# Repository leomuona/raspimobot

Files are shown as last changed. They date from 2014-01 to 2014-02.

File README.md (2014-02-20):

raspimobot
==========

This software project was done for the course Intelligent Embedded System (id 582711) at the CS Department of the University of Helsinki. The course was held during Spring term 2014, third period.

raspimobot is a Raspberry Pi robot that uses camera module and L293D motor control chip to control a single motor. The robot detects movement with the camera and turns the camera (with the motor) towards the movement position. It also supports the use of .wav audio files to greet the person that causes the movement.

This code is under GPLv3 license, please check the LICENSE file for more information.

We used the following libraries and documentation for the project, also includes our demo video:

WiringPi for GPIO controls: http://wiringpi.org

Raspberry Pi userland code for the camera: https://github.com/raspberrypi/userland

Raspberry Pi documentation: http://elinux.org/RPi_Hub

Our demonstration video: http://www.youtube.com/watch?v=bQQ_EZM07OI

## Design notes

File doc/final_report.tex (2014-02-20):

\documentclass[english,11pt,twoside,a4paper]{article}
\usepackage[left=2cm,top=1cm,right=2cm,nohead,nofoot]{geometry}
\usepackage[utf8]{inputenc}
\usepackage{hyperref}
\usepackage{amssymb}
\usepackage{graphicx}
\usepackage{titling}
\newcommand{\subtitle}[1]{%
  \posttitle{%
    \par\end{center}
    \begin{center}\large#1\end{center}
    \vskip0.5em}%
}

\begin{document}
\author{
  Niemistö, Jesse
  \and
  Muona, Leo
  \and
  Hilden, Matias
}
\title{Raspberry Pi robot}
\subtitle{Intelligent Embedded Systems - Final report}

\maketitle

\tableofcontents

\section{Introduction}

This is a final report for the course Intelligent Embedded System (id 582711) at the CS Department of the University of Helsinki. This course was held during Spring term 2014, third period. The course is a self-study course that consists of an embedded systems project. For our project we chose to build a Raspberry Pi robot, which utilizes Pi's camera module, audio output and electric DC motors.

Raspberry Pi is a cheap arm-computer that was originally created for the purpose to help more people to get into programming. We chose to use this one-chip-computer for our project because it runs on Linux (among other operating systems), it has a camera module available, it has GPIO pins for controlling a motor control chip, and all of our team members already had one lying around.

This document includes our project idea, requirements and initial design for the robot, implementation of the robot, evaluation of our project, and a summary of lessons learned. This is the tale of our awesome little raspi robot.

\section{The idea}

We got our initial idea from the video game Portal by Valve Corp. In the game, there were these "cute" robot turrets that recognized movement, talked to the source of the movement and shot them. So our initial idea was to create a robot similar to these turrets, so that we will use Raspberry Pi's camera module to recognize movement, target the movement source, and play a random audio clip to greet the source of the movement.

Our initial idea had two DC motors to control the turret's movement and a laser- or LED-pointer to point the target. However this idea evolved during the project just to use one motor and only turn the camera towards the movement source.

\section{Requirements and initial design}

At the start of our project we wrote our requirements and then initial design. The design consists more on actual planning of hardware part than the code to be created. This section can be divided into five parts: required features, audio system design, camera design, motor control system design, and software design.

\subsection{Required features}

These were the required features at the start of our project when designing the robot:

\begin{itemize}
  \item Horizontal and vertical rotational movement.
  \item WAV (or ogg) audio playback.
  \item Motion detection based on frame difference algorithm.
  \item Aiming at detected movement.
  \item Remote control.
  \item Works on top of Linux.
\end{itemize}

We used these features a guideline for our project design. At this stage it is good to mention that some of these features were modified during the project.

\subsection{Audio design}
\label{sec:audio_design}

For audio we used the 3.5mm jack audio output connector on the Raspberry Pi with our self-built audio amplifier, which is connected to a single speaker. The single speaker can only output mono audio, but this won't matter since audio contains only speaking. The used speaker was small and low powered. We also made a simple audio jack connector. This was made with a bought 3.5mm mono jack connector, which was soldered to ground and audio.

\begin{figure}
  \begin{center}
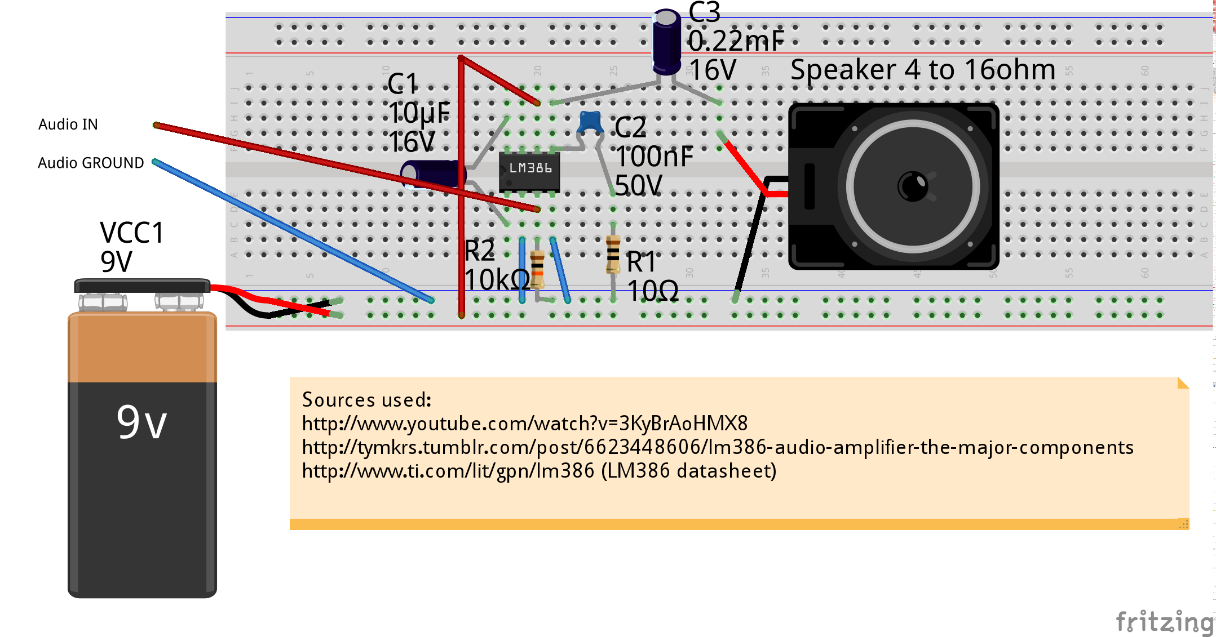
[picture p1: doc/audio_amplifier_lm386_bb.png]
    
    \caption{Breadboard view for the audio amplifier.}
  \end{center}
  \label{lm386_bb}
\end{figure}

In the heart of the audio amplifier stands the LM386 circuit, which is a "Low Voltage Audio Power Amplifier" and was more than enough for our use case. The figure in~\ref{lm386_bb} shows the breadboard view that we used used for the audio amplifier. The build is same to that what is shown on the LM386 datasheet, "amplifier with Gain = 200".

\begin{itemize}
  \item Between PINs 1 and 8 is a 10uF capacitor, which causes a gain on 200. In desibels this is around 20.
  \item PIN 2 is places to ground.
  \item PIN 3 takes the audio input, and is connected to ground through 10k ohm resistor.
  \item PIN 4 is placed to ground.
  \item PIN 5 is the amplified audio output.
  \item PIN 6 takes power
  \item PIN 7 is bybassed, doesn't take connection.
\end{itemize}

\subsection{Camera design}

We decided to use a simple plug-in Raspberry Pi camera module, which we will use to take pictures that we compare to previous ones to detect movement. Since Raspberry Pi has a ready-to-use socket for camera cable, no extra cables or power supplies are needed. To use the camera we will use \href{https://github.com/raspberrypi/userland}{Pi's Userland code}, that comes with raspistill-program which we can use to take still pictures.

\subsection{Motor control design}

To control the motors, we planned our design around L293D motor control chip, which is cheap and easily available. Our design consisted of two motors, one to turn the camera horizontally and one to turn the camera vertically. This design used two L293D chips, one for each motor.

\begin{figure}
  \begin{center}
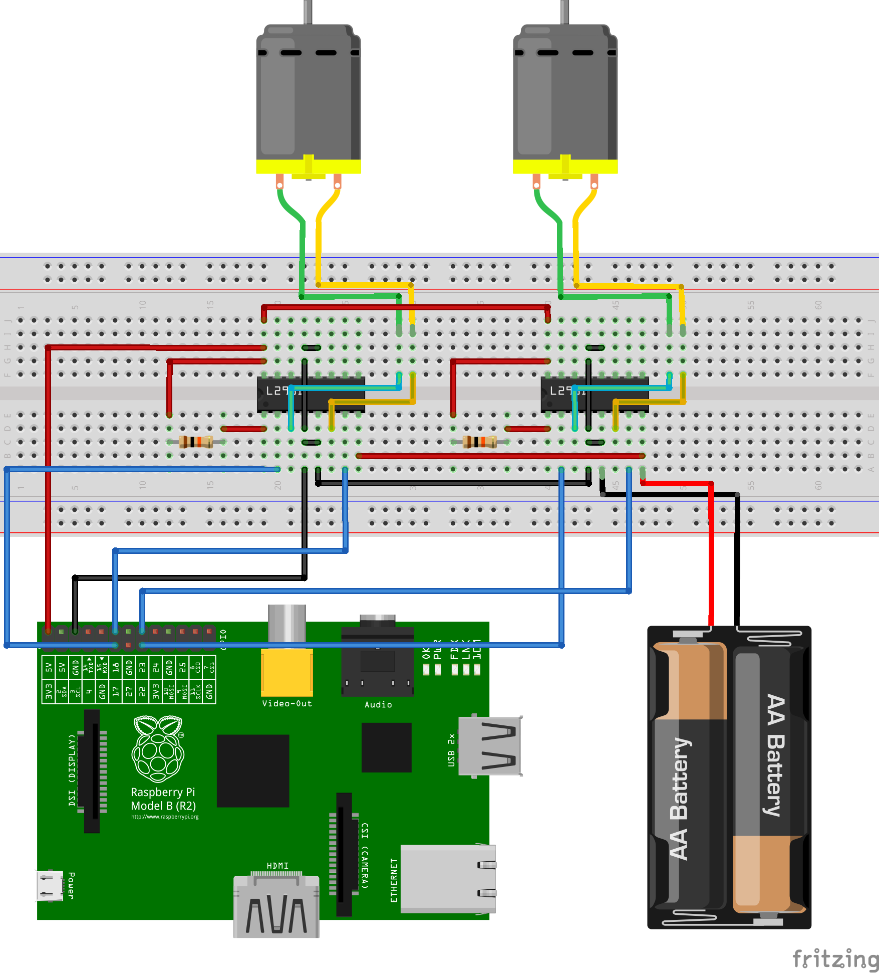
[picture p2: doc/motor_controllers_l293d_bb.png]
    
    \caption{Motor controllers design in breadboard view.}
  \end{center}
  \label{l293d_bb_design}
\end{figure}

Figure \ref{l293d_bb_design} shows how the chips would be connected into the Raspberry Pi. Design uses GPIO pins 17 and 18 to control the first motor and pins 22 and 23 to control the second motor. The two AA batteries will supply power for both of the motors, and Raspberry Pi will supply power for the motor control chips.

\subsection{Software design}

Our project requires software for three main things: camera control, audio control and motor control. Even though we use a ready-to-use software to take pictures with the camera, we need to write our own software for image analysis, that is used to detect movement in the camera. We will write our own audio playback code against pulseaudio sound server. As for sound files, we are planning to use .ogg files. For the motor controlling we plan to use either direct /dev/mem code, or an additional \href{http://wiringpi.com}{WiringPi gpio library} to control the GPIO pins.

We will also write other code, like the logical code for the whole software, threading for different parts, and a remote control code for testing purposes. And hopefully we don't need to write multiple hacks.

\section{Implementation}

For the implementation, we ran into few problems along the way. Implementation was divided into three separate parts: motor related stuff, audio related stuff and camera related stuff. These parts were implemented as paraller. During the implementation, few features needed some modification and later of the project timetable few "nasty" code and hacks were implemented to get the wanted results.

\subsection{Audio}

The implementation of the audio amplifier required bying the parts and assembling them. There weren't really any problems with this, and everything worked as was planned. Refer to chapter~\ref{sec:audio_design} for what was the plan.

The speaker didn't require any assembling but was simply connected to the audio amplifier. For the case of our speaker we used a beer can. Twas used for flavor.

The software part wasn't that easy. We used Pulseaudio audio system for interacting with the underlying audio hardware. We decided to use the Pulseaudio provided Threaded API, as we wanted to play sounds in a non-blocking way. The Initial implementation worked well on test cases, and on development computers. However, when moved to the actual enviroment, which was Raspberry Pi under load, the problems started. Firstly, Pulseaudio allows under no conditions connections from a root user. This caused a few problems as our software at the time required root user (wiring Pi actually). After working around this (dropping root), we noticed that audio was crackling as Raspberry Pi couldn't handle all the load. This required making some things sleep during audio playback.

This wasn't all thought. It seems that at least on the current Raspberry Pi board something with the audio driver or Pulseaudio was bugging, and the whole audio playback would jam for some unknown reason. Working around this actually required a erally evil workaround. Luckily all our samples were really short (under three seconds), so if we notice that three seconds has passed by and our audio subsystem says it is still playing, we send SIGINT to pulseaudio to kill the connection. This made it possible that our robot is able to continue its smooth operation.

\subsection{Motor control system}

Largest modifications to the design had to be done to the motor controlling system. After implementing the planned two-motor-system, we noticed that it would be hard to create correct platform that would be aimed in two dimensions. In addition to this, we noticed that we couldn't implement the correct calculations for vertical movement during project's timetable. Thus we changed the motor system to use only horizontal motor.

\begin{figure}
  \begin{center}
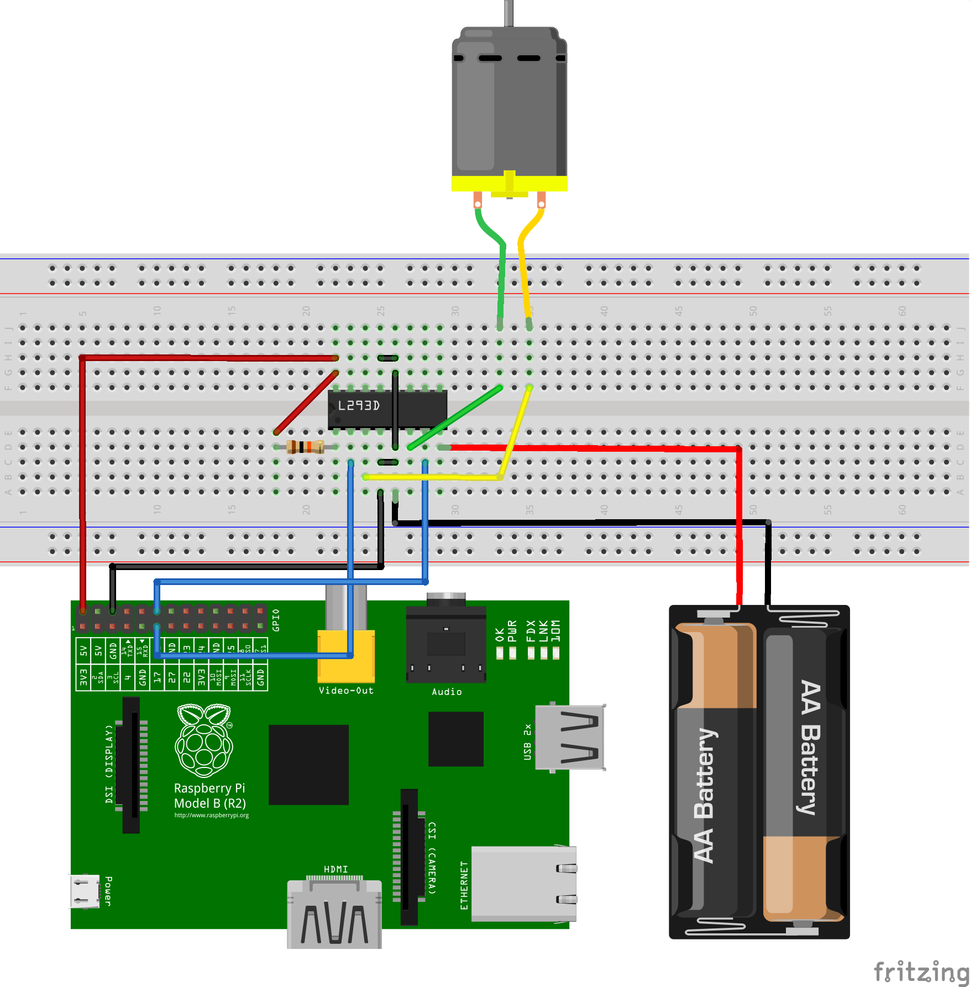
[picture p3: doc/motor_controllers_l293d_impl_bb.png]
    
    \caption{Motor controller implementation in breadboard view.}
  \end{center}
  \label{l293d_bb_impl}
\end{figure}

The hardware implementation of our motor system is shown in figure \ref{l293d_bb_impl}. The AA batteries now have to supply only one motor, and we had to implement code for only two GPIO pins. The L293D motor control chip we used gets it's VCC1 power from Raspberry Pi's 5V pin, and uses that same line trought a 10k ohm resistor to give the enable signal for our motor chip.

Motor control's software had some changes as well. After we started to use \href{http://wiringpi.com}{WiringPi library} the software had to be run as root, as it was WiringPi's requirement. This caused us some problems with pulseaudio, which has a lot of problems when run as root. A fix to this was to remove WiringPi linking from our software and add WiringPi library only as a system requirement. That is, it should be installed on the Raspberry Pi normally. Then we used system calls to use gpio-program, that was bundled with WiringPi and could be run in non-root environments. This is one of the hacks we had to do to get things working.

\subsection{Camera}

Implementing the taking of pictures was not a problem due to the usage of raspistill-program. The program turned to not be optimal for continual usage but served our purposes well enough. Image difference calculation and rotation angle calculation were purely mathematical algorithms and thus did not need to interact with Raspberry Pi hardware. This made their implementation quite straightforward.

\section{Evaluation}

Motor controlling system worked well. Mainly due to the hack we made and the fact that the L293D chip is a pretty simple control chip. Using the GPIO pins is pretty straight forward with the WiringPi library. Only bad thing in the motor control system implementation is that we had to downgrade our project to use only one motor instead of two.

Audio amplifier, when connected to the speaker had suprisingly good sound and volume. Actually we had to drop the volume to one fourth of what was the full volume not to break our ears. The speaker in a can outputted a good and clear sound, better than any of us could have hoped for.

However, when audio jack is not connected, and even sometimes when connected, the audio amplifier and speaker takes audible interference. A high-piched noise that eats into your mind. There were a few workarounds, that mostly was duct taping the wires together which acted as a shield for the wires.

The software side of the Audio, when coupled with the hacks it required, works quite well. At times one can notice that the hardware can't really handle all the load, and audio makes a few cracks. We really shouldn't also have used Pulseaudio Threaded API. This mostly adds overhead, especially since Raspberry Pi is a single processor system.

\section{Summary}

The project started with a funny idea. And the idea continued to live on through the project. Thus all team members agree that this project a great success. There were few hacks along the way and few features had to be modified or dropped, but the robot still was quite similar as the initial idea. Our internal project timetable actually went pretty badly, because implementation took way more time than we originally though. However we were able to get the robot in a complete state.

When analyzing the keys to success, this that comes to mind is the fact that all team members knew each others beforehand, and the project was really fun to work with. Also the amount of documentation for the Raspberry Pi helped alot.

\section{Links}

\begin{itemize}
  \item Demonstration video: \url{http://www.youtube.com/watch?v=bQQ_EZM07OI}
  \item Project github repository: \url{https://github.com/domewolf/raspimobot}
  \item Raspberry Pi userland repository (contains raspistill): \url{https://github.com/raspberrypi/userland}
  \item WiringPi homepage: \url{https://projects.drogon.net/raspberry-pi/wiringpi/}
  \item Raspberry Pi documentations: \url{http://elinux.org/RPi_Hub}
\end{itemize}

\end{document}

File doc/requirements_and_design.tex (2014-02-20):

\documentclass[english,11pt,twoside,a4paper]{article}
\usepackage[left=2cm,top=1cm,right=2cm,nohead,nofoot]{geometry}
\usepackage[utf8]{inputenc}
\usepackage{hyperref}
\usepackage{amssymb}
\usepackage{graphicx}
\begin{document}
\author{
  Niemistö, Jesse
  \and
  Muona, Leo
  \and
  Hilden, Matias
}
\title{Requirements and design}

\maketitle

\section{Introduction}
This document includes requirements, features and design of our turret for Intelligent Embedded Systems -course (University of Helsinki course number 582711). For our project we chose to create an "intelligent" turret inspired by video game Portal by Valve Company. This document describes the intended features that our turret will have. This includes different subsections of the project, including audio output, camera input, DC motor control system and software.

\section{Features}

Robot will have the following features:

\begin{itemize}
  \item Horizontal and vertical rotational movement.
  \item WAV (or ogg) audio playback.
  \item Motion detection based on frame difference algorithm.
  \item Aiming at detected movement.
  \item Remote control.
  \item Works on top of Linux.
\end{itemize}

\section{Audio}

For audio we will be using the 3.5mm jack audio output connector on the raspberry pi. However, instead of connecting just some ready stereo system, we'll build our own audio amplifier, which is connected to a single speaker. Thus we'll only need to output mono audio. Since audio will mostly contain speaking, it does not matter. The used speaker will be small and low powered.

To be able to use our audio amplifier on the raspberry pi, we need to make a simple connector, which is quite simple. We only need to get a male 3.5mm jack connector, ignore the possible second audio output (incase of stereo), and solder our two needed wires on it (ground and audio out).

\begin{figure}
  \begin{center}
    
    \caption{Breadboard view for the audio amplifier.}
  \end{center}
  \label{lm386_bb}
\end{figure}

In the heart of the audio amplifier stands the LM386 circuit, which is a "Low Voltage Audio Power Amplifier" and is more than enough for our use case. The figure in~\ref{lm386_bb} shows the breadboard view that we'll be using for the audio amplifier. The build is same to that what is shown on the LM386 datasheet, "amplifier with Gain = 200".

\begin{itemize}
  \item Between PINs 1 and 8 is a 10uF capacitor, which causes a gain on 200. In desibels this is around 20. 
  \item PIN 2 is places to ground.
  \item PIN 3 takes the audio input, and is connected to ground through 10k ohm resistor.
  \item PIN 4 is placed to ground.
  \item PIN 5 is the amplified audio output.
  \item PIN 6 takes power
  \item PIN 7 is bybassed, doesn't take connection.
\end{itemize}

\section{Camera}
Raspberry Pi Camera Board (https://www.element14.com/picamera) will be used for motion detection together with Raspberry Pi Userland code (https://github.com/raspberrypi/userland). At first, pictures will be taken using the raspistill-program provided by Userland. If we have time, we will integrate the camera code to be part of the other code, thus allowing us to strip all the unneeded features of userland.

Raspberry Pi has a camera socket intended for the camera, so no other electronic components are required in addition to the camera.

\section{Motors}
Lets assume that the turret has a weapon. In implementation the weapon will probably be either a laser pointer or an LED light. Moving the aim into correct position is done by two small DC motors, one for horizontal and one for vertical movement. Raspberry Pi will be controlling the motors via it's PCIO pins.

\begin{figure}
  \begin{center}
    
    \caption{Breadboard view for motor controllers.}
  \end{center}
  \label{l293d_bb}
\end{figure}

Our design uses two L293D motor controller chips for controlling the two motors. The breadboard design in figure \ref{l293d_bb} visualizes more closely on how the L293D chips are connected to Raspberry Pi, motors and additional battery power supply. The design shows how Raspberry Pi's GPIO pins 17 and 18 are used to control the first DC motor, and pins 22 and 23 are used to control the second one. L293D chips will get their VCC1 powers from the 5V Raspberry Pi pin, and their enable powers from the same pin, but trough 10 kilo ohm resistors. The motors will use power from two AA batteries, that give total of 3V voltage for the motors. Power for the motors are given through L293D chip's VCC2 pin.

A compact list for L293D chip's pin usage is the following:
\begin{itemize}
\item Pin 1: Enable signal for control signals \#1 and \#2.
\item Pin 2: Control signal \#1 input from Raspberry Pi.
\item Pin 3: Output current \#1 for the DC motor.
\item Pins 4-5: Ground 0V.
\item Pin 6: Control signal \#2 input from Raspberry Pi.
\item Pin 7: Output current \#2 for the DC motor.
\item Pin 8: VCC2 input, this is the motor's power current.
\item Pins 12-13: Ground 0V.
\item Pin 16: VCC1 power current for the 293D chip.
\end{itemize}

L293D motor control chip makes the DC motor turn left and right when control signals \#1 and \#2 from Raspberry Pi are in different states. If both of them are either low or high, the motor is stopped.

In order to test this design, we will code a simple testing software that gives correct signals from correct Raspberry Pi pins. After the software and signals are tested, then we will attach motor control chips into test bench to test how electronics work while connected. Only after these steps we can assemble our turret's mechanical parts.

\section{Software}
In addition to camera software provided by Raspberry Pi, we will write our own software for image analysis (motion detection), audio playback and motor movement. We will also write a remote control software for testing purposes at some point.

Our audio playback will be coded against pulseaudio sound server. The reason being, that it provides better API than ALSA. For example, there is \href{http://freedesktop.org/software/pulseaudio/doxygen/scache.html}{Sample cache} on the server side, which does sound optimal to what we're planning. We're planning to use ogg for audio files, but we'll see how it goes. We're not sure how much the Arm CPU of the Raspberry Pi can handle, adding ogg decoder on top of everything else might be too much. The first step is to just get somehow working nonblocking audio playback.

Our motor controlling code will use either direct access to /dev/mem or if that does not work, we will use a third party open source library, like \href{http://wiringpi.com/}{WiringPi}.

\end{document}

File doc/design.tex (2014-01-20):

\documentclass[english,11pt,twoside,a4paper]{article}
\usepackage[left=2cm,top=1cm,right=2cm,nohead,nofoot]{geometry}
\usepackage[utf8]{inputenc}
\usepackage{hyperref}
\usepackage{amssymb}
\usepackage{graphicx}
\begin{document}
\author{
  Niemistö, Jesse
  \and
  Muona, Leo
  \and
  Hilden, Matias
}
\title{Conceptual Design}

\maketitle

\section{Project idea}

Our aim in this project is to make a turret, which aims moving targets with laser pointer, and makes appropriate noises. This means that the turret will have following parts:

\begin{itemize}
  \item Raspberry Pi, the main controller. It holds the main software under Linux OS.
  \item Two DC motors (\url{http://www.kouluelektroniikka.fi/cgi-bin/shop.cg?action=prodshow\&usr=3qienj42dm87vuhhkuuv9nst84\&prodid=5561\%20545}), one for horizontal tracking and one for vertical tracking.
  \item Motor control circuit (L293D), which is able to control both motors.
  \item Camera (Raspberry Pi NoIR ccd camera module 5MPx), which is used for tracking movements.
  \item Circuit board, which is used for connections.
  \item Speaker (\url{http://www.partco.biz/verkkokauppa/product\_info.php?cath=17\_1440\_1916\&products\_id=1086})
  \item Audio amplifier, (LM386, something like \href{http://www.youtube.com/watch?v=3KyBrAoHMX8}{this}) which is used with the speaker to produce audio output.
\end{itemize}

Our initial design consists of a static base, which has a horizontally rotating platform on top of it. This platform is rotated via one DC motor. On the platform we plan to mount the second DC motor, which has a laser pointer's base attached to it. This base is rotated vertically. Both DC motors are controlled by the Raspberry Pi via motor control circuit L293D.

We plan the software to have the following functionalities:

\begin{itemize}
  \item Movement detection via the camera.
  \item Greeting a person that is causing the movement with a common greeting.
  \item Aiming the laser pointer at the person that was detected.
  \item When movement has stopped, asking the person if he/she is still there.
  \item Playing extra sounds to make the turret more fun.
\end{itemize}

Inspiration for the project is from the game Portal by Valve Corporation. The game has white cute military turrets that try to kill the game's protagonist.

\begin{figure}
  \begin{center}
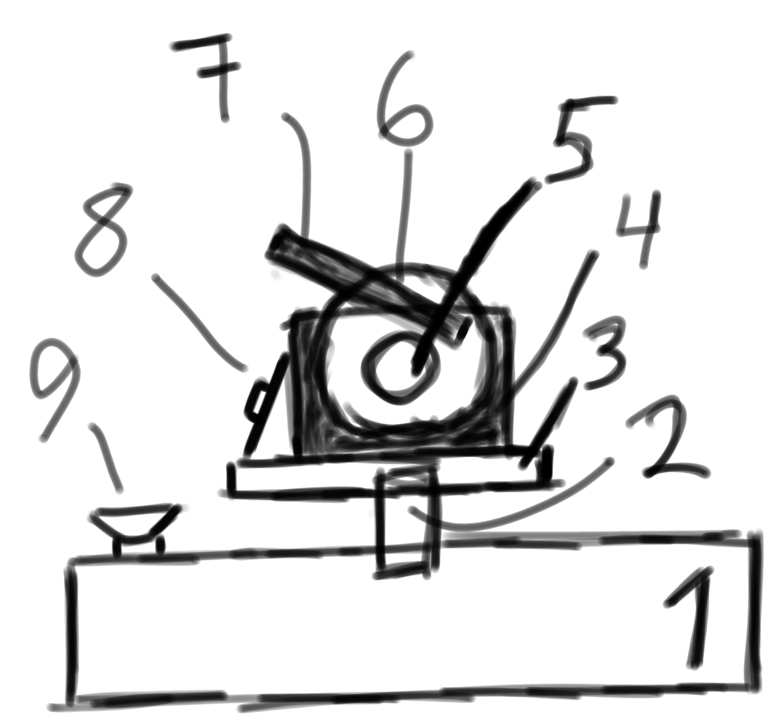
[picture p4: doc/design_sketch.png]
    
    \caption{Rough sketch of the design.}
  \end{center}
  \label{sketch}
\end{figure}

Figure~\ref{sketch} shows the rough design of the turret. The numbered parts are following.

\begin{enumerate}
  \item Raspberry pi, works also as the base for the turret.
  \item DC Motor.
  \item Platform that is rotated vertically by the DC motor of item 2.
  \item Random block of unknown material that is used as a base for item 5. Is attached to item 3.
  \item DC Motor, attached to block in item 4.
  \item Platform that is rotated horizontally by the DC motor of item 5.
  \item Pointing device (A Laser-like LED light), attached to platform of item 6.
  \item Camera unit, stands on top of platform of item 3.
  \item Speaker, on top of Raspberry pi.
\end{enumerate}

\section{Project timetable}

We plan to complete the project according to the following timetable.

\begin{itemize}
  \item \textbf{Requirements and design} document should be completed at the end of week 4.
  \item \textbf{Implementation} includes assembling and coding. Assembling should be completed during week 5, and coding should be done during weeks 5 and 6.
  \item \textbf{Evaluation} document should be completed during week 7.
  \item \textbf{Demonstration} can be done during week 7 or as soon as implementation is done.
  \item \textbf{Final report} should be written during weeks 7 and 8. Note that the project deadline is February 20th, which is Thursday of week 8. So week 8 only counts three days for our project.
\end{itemize}

As can be seen from the timetable, the schedule is really tight. This is one of the biggest risks of this project, because there is no room for delays.

\end{document}

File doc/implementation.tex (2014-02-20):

\documentclass[english,11pt,twoside,a4paper]{article}
\usepackage[left=2cm,top=1cm,right=2cm,nohead,nofoot]{geometry}
\usepackage[utf8]{inputenc}
\usepackage{hyperref}
\usepackage{amssymb}
\usepackage{graphicx}
\usepackage{algorithm}
\usepackage{algorithmic}
\begin{document}
\author{
  Niemistö, Jesse
  \and
  Muona, Leo
  \and
  Hilden, Matias
}
\title{Implementation}

\maketitle

\section{Software}

Our software works on top of Linux OS. Our implementation language was C and compiler used was GCC. We use \href{https://projects.drogon.net/raspberry-pi/wiringpi/}{wiring Pi} for talking with Raspberry Pi GPIO, Pulseaudio for playing PCM audio and sndfile for reading WAV files. We also use Raspberry Pi userland program "raspistill" to take pictures with the camera module.

\subsection{Main loop}

\begin{algorithm}
  \label{mainloop}
  \caption{main loop}
  \begin{algorithmic}
    \IF {!(old picture has been taken)}
      \STATE takePicture(old picture)
    \ELSIF {!(new picture has been taken)}
      \STATE takePicture(new picture)
    \ELSE
      \STATE new picture = old picture
      \STATE takePicture(new picture)
    \ENDIF

    \IF {old picture and new picture have been taken}
      \STATE diff = doMotionDetection(old picture, new picture)
      \IF {detected motion in diff}
        \STATE horizontal, vertical = doCalcRotation(diff)
        \STATE rotateMotorX(horizontal)
        \STATE rotateMotorY(vertical)
        \IF {!(is some sound playing)}
          \STATE play some sound effect
        \ENDIF
	\STATE old picture = NULL
	\STATE new picture = NULL
      \ENDIF
    \ENDIF
  \end{algorithmic}
\end{algorithm}

The algoritm in~\ref{mainloop} shows our main loop that is iterated over and over again. The tests for old and new pictures are part of the initialization routine. We need to take at least to picture to be able to look for motion. After new and old pictures have been taken, we can use the newer picture as the older picture, and take only one picture. If, however, we detected motion and moved our motors, both pictures need to be taken again, for the reasons that the delta time is too great between the pictures, and camera viewpoint has changed.

\subsection{Motion detection algorithm}

\begin{algorithm}
  \label{motiondetection}
  \caption{Motion detection $diff = a - b$}
  \begin{algorithmic}
    \STATE \COMMENT{First-pass marks the pixels that are changed}
    \STATE init(first pass)
    \FORALL {pixels in a and b}
      \STATE diff = abs(pixel(a) - pixel(b)))
      \IF {diff $>=$ difference threshold}
        \STATE mark pixel as changed in first pass
      \ENDIF
    \ENDFOR

    \STATE \COMMENT{Second-pass is erosion filter $=>$ ignore minor differences}
    \STATE init(second pass)
    \STATE n = ((noise filter size) - 1)/2
    \FORALL {pixels in a and b}
      \STATE count the number of marked pixels in current window
      \IF {marked pixels $>=$ noise filter size}
        \STATE mark pixels as changed in second pass
      \ENDIF
    \ENDFOR

  \end{algorithmic}
\end{algorithm}

The motion detection routine in~\ref{motiondetection} is extremely simple and naive. We do the checks by comparing pixel values between two different images. This means that even smallest jolt to our base causes the motion detection to completely fail. Then again the center of the movement is then centered and it doesn't matter that much.

We have two variables to adjust the detection algorithm. Difference threshold and noise filter size. Difference threshold is used to check if given pixel has been changed. If the difference of the given pixels is greater than difference threshold, then the pixel is assumed as changed. Noise filter is used to filter out single pixel differences, that passed difference threshold. This in effect requires that motion differences come in blocks, rather than singles. Making this setting too high makes the code extremely inefficient.

In essence, the motion detection algorithm takes two pictures with camera, compares the images pixel by pixel basis and filters out differences caused by noise. The motion is expected to be found from the center of the found motion frame.

\subsection {Rotation angle calculation}

\begin{algorithm}
  \label{rotationanglecalc}
  \caption{Rotation angle $diff$}
  \begin{algorithmic}
    \IF {diff $>$ 0}
      \STATE \COMMENT{calculate the center of different pixels}
      \STATE centerx = (diff.minx + diff.maxx) / 2
      \STATE centery = (diff.miny + diff.maxy) / 2
      \IF {centerx $!=$ middlex AND centery $!=$ middley}
        \STATE \COMMENT{calculate center relation to middle and closest edge}
	\STATE relationx = centerx / middlex - 1
	\STATE relationy = centery / middley - 1
	\STATE \COMMENT{return relative rotation angle times angle of view}
	\STATE horizontalangle = relationx * horizontalangleofview / 2
	\STATE verticalangle = relationy * verticalangleofview / 2
      \ENDIF
    \ENDIF
  \end{algorithmic}
\end{algorithm}

The purpose of this algorithm is to calculate to rotation angles needed in order to face the center of motion. Results of this algorithm are passed straight to the motor code.

When motion detection algorithm has calculated the difference between two pictures, the result is passed to this rotation angle calculation algorithm. It calculates the center of difference by taking average of the most left and right pixels and average of the most bottom and top pixels. Then it calculates the relative distances to the center of the picture and edges from those pixels. As we know the angles of view for the camera module from technical specifications, the rotation angles can be calculated by multiplying the relative distances with halved angles of view.

\subsection{Motor control}

Motor controlling is done via Raspberry Pi's GPIO pins. To control one motor, we are using two pins that have high and low output signals. In order to control the pins, we are using \href{http://wiringpi.com/}{WiringPi C library}.

At first we linked the C library into our project and included WiringPi.h. However, because it required us to run our software as root, we could not get the pulseaudio sound working at the same time. As a fix WiringPi C library is now only a system requirement and we are using system calls instead of linking the library. System calls use WiringPi's gpio commands.

\section{Hardware}

Our hardware consists of Raspberry Pi v2 (512 MB model), Raspberry Pi camera module, a self-made sound output speaker system and our motor system. We are using Pi's 3.5mm headphone jack for sound output and GPIO pins for motor controlling.

\subsection{Sound speaker system}

For audio we used the 3.5mm jack audio output connector on the raspberry pi with our self-built audio amplifier, which is connected to a single speaker. The single speaker can only output mono audio, but this won't matter since audio contains only speaking. The used speaker was small and low powered. We also made a simple audio jack connector. This was made with a bought 3.5mm mono jack connector, which was soldered to ground and audio.

\begin{figure}
  \begin{center}
    
    \caption{Breadboard view for the audio amplifier.}
  \end{center}
  \label{lm386_bb}
\end{figure}

In the heart of the audio amplifier stands the LM386 circuit, which is a "Low Voltage Audio Power Amplifier" and was more than enough for our use case. The figure in~\ref{lm386_bb} shows the breadboard view that we used used for the audio amplifier. The build is same to that what is shown on the LM386 datasheet, "amplifier with Gain = 200".

\begin{itemize}
  \item Between PINs 1 and 8 is a 10uF capacitor, which causes a gain on 200. In desibels this is around 20.
  \item PIN 2 is places to ground.
  \item PIN 3 takes the audio input, and is connected to ground through 10k ohm resistor.
  \item PIN 4 is placed to ground.
  \item PIN 5 is the amplified audio output.
  \item PIN 6 takes power
  \item PIN 7 is bybassed, doesn't take connection.
\end{itemize}

There weren't really any problems in assembling hardware, and everything with it worked as was planned.

\subsection{Motor control system}

Our motor control system consists of L293D motor control chip, 10k ohm resistor, battery case for two AA batteries and a small DC motor that has gears to lower main axis angular velocity. The parts are connected to each others as shown in figure \ref{l293d_bb}.

\begin{figure}
  \begin{center}
    
    \caption{Breadboard view for motor controller.}
  \end{center}
  \label{l293d_bb}
\end{figure}

The L293D control chip gets it's operating power (VCC1) from Raspberry Pi 5V gpio pin. It also uses the same power through the transistor to send enable signal for motor controlling unit 1. The DC motor gets it's operating power from two AA batteries (3V) via L293D control chip's VCC2 pin.

\begin{table}
  \begin{center}
    \begin{tabular}{| l | l | l | l |}
      \hline
      Enable signal & Input 1A & Input 2A & Function \\ \hline
      H & L & H & Turn right \\ \hline
      H & H & L & Turn left \\ \hline
	  H & L & L & Stop \\ \hline
	  H & H & H & Stop \\ \hline
	  L & any & any & Stop \\ \hline
    \end{tabular}
    \caption{L293D chip's signal table. H = High, L = Low.}
  \end{center}
  \label{l293d_signal_table}
\end{table}

Raspberry Pi's GPIO pins 17 and 18 (hardware pins 11 and 12) high and low signals control the motor via L293D control chip. As shown in table \ref{l293d_signal_table}, the motor will rotate only when pin signals differ from each other. The enable signal is on at all times, since it is connected with a resistor to chip's VCC1.

\end{document}

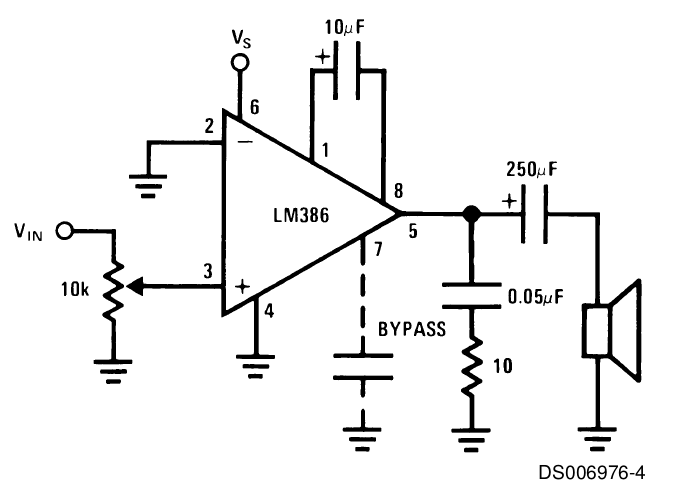
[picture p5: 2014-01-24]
doc/audio_amplifier_lm386_schematics.png

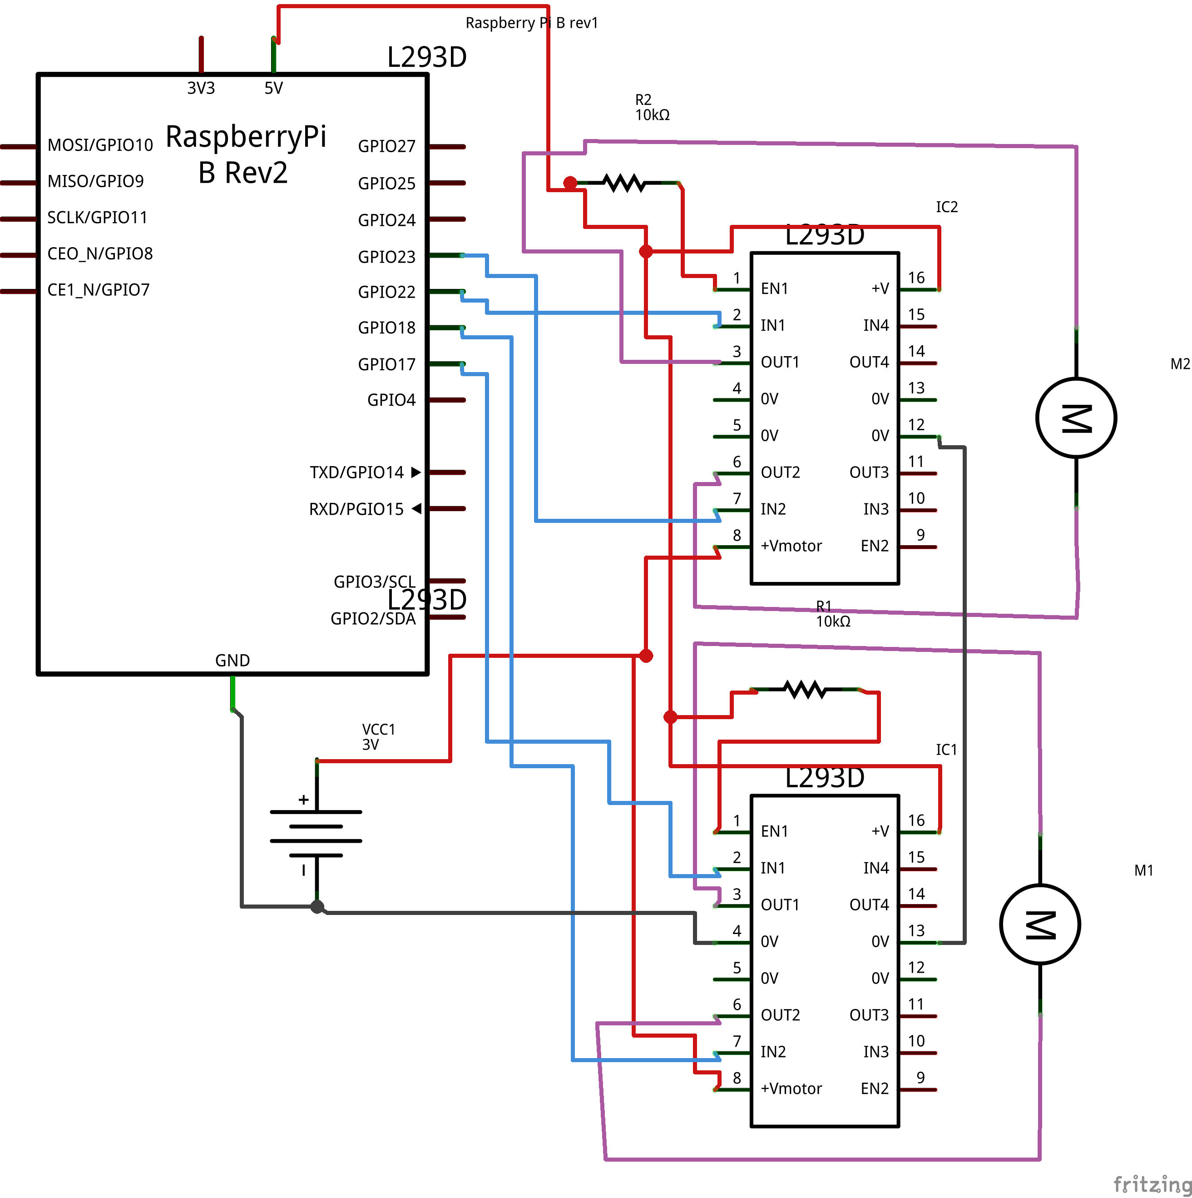
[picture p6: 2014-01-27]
doc/motor_controllers_l293d_schem.png

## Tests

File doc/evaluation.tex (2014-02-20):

\documentclass[english,11pt,twoside,a4paper]{article}
\usepackage[left=2cm,top=1cm,right=2cm,nohead,nofoot]{geometry}
\usepackage[utf8]{inputenc}
\usepackage{hyperref}
\usepackage{amssymb}
\usepackage{graphicx}
\begin{document}
\author{
  Niemistö, Jesse
  \and
  Muona, Leo
  \and
  Hilden, Matias
}
\title{Evaluation}

\maketitle

\section{Dropped features}

Due to both algorithmic and mechanical difficulties, we had to drop the vertical rotation motor.

\section{Testing}

We performed two kind of tests on the project: Use case tests for determing wether the prototype works as intended, and perfomance testing to measure cycle speed during rest (no motion) and calculation (motion).

\subsection{Use case testing}

Use case testing is done in a room where at the start of the test the system has been initialized and program ran. Motor rotation at the initialization should be at the center of robot. Use case tests are identified with UC-prefix and index number suffix.

\textbf{UC-1: No motion test}

The first use case test is a test where no movement is at camera's field of view. The correct result is camera taking pictures (indicated via red blinking light) and no movement by the motor or sound from the audio system is played. The test result was successful. 

\textbf{UC-2: Left-side motion test}

The second use case test is a test where there is a single movement at left side of camera's field of view. Correct result contains the following characteristics:

\begin{itemize}
  \item Camera: Takes two pictures from which the movement is recognized. Then halts the picture taking for the time of motor rotation.
  \item Sound: A random sound clip is played to greet the person who has done the movement.
  \item Motor: Motor axis rotates the camera to left so that the center of camera points at movement spot.
\end{itemize}

The test result was "okay". That is, the correct motor rotation was made and soundclip was played. However targetting is not very accurate.

\textbf{UC-3: Right-side motion test}

The third use case test is a test where there is a single movement at right side of camera's field of view. Correct result contains the following characteristics:

\begin{itemize}
  \item Camera: Takes two pictures from which the movement is recognized. Then halts the picture taking for the time of motor rotation.
  \item Sound: A random sound clip is played to greet the person who has done the movement.
  \item Motor: Motor axis rotates the camera to right so that center of camera points at movement spot.
\end{itemize}

The test result was "okay". Rotation was made towards the correct spot and soundclip was played. However, like in previous test, targetting is not very accurate.

\textbf{UC-4: Maximum rotation test}

The fourth use case test is a test to check maximum rotation edges. This test includes movement done first on the left side of the camera, just in camera's field of view, multiple times untill camera no longer rotates to left. Then, same is done at the right side of the camera's field of view untill camera has turned multiple times untill camera no longer rotates to right. Test case correct result includes the following:

\begin{itemize}
  \item Camera: Takes pictures every time movement is recognized.
  \item Sound: Plays audio clip every time movement is recognized.
  \item Motor: Camera turns left multiple times when movement is recognized, then stops at 30 degrees from the center, which is the safe limit. When movement is done at the right side of camera, camera turns right multiple times when movement is recognized, then stops at 30 degrees from the center, which is the safe limit.
\end{itemize}

Test result was successful. As a sidenote, when running the test case again, the camera moves different lengths at a time.

\subsection{Performance testing}

Perfomance tests will programmically time the length picture cycles. Each cycle contains the following: taking a new picture, calculating differences between old and new pictures and calculating the rotation angle in case motion was detected. Rotation and audio playback are left out of the cycle as they depend on rotation and audio file length, thus impacting the results in a non-informative way.

The time used by the program "raspistill" was externally measured to be around 1200 milliseconds. This result is used when analyzing cycle performance below.

\textbf{No motion}

The turret was set to watch a direction with no motion and the program was started. The results in table \ref{cycle_times_no_motion}

\begin{table}[ht]
  \begin{center}
    \begin{tabular}{| l | l |}
      \hline
      Cycle number & Length in milliseconds \\ \hline
      01 & 3101 \\ \hline
      02 & 1927 \\ \hline
      03 & 1929 \\ \hline
      04 & 1930 \\ \hline
      05 & 1927 \\ \hline
      06 & 1928 \\ \hline
      07 & 1933 \\ \hline
      08 & 1959 \\ \hline
      09 & 1928 \\ \hline
      10 & 1943 \\ \hline
    \end{tabular}
    \caption{Cycle times with no motion}
  \end{center}
  \label{cycle_times_no_motion}
\end{table}

The first cycle takes approximately twice as long as other cycles because the program takes two pictures in a row. Excluding that first cycle, the cycle time average is 1927 milliseconds. As the raspistill call takes about 1200 milliseconds, our difference calculation algorithm seems to take about 700 milliseconds. Cycle time is more than we would like, but still within acceptable limits.

\textbf{Motion}

The turret was set to watch one of our project members who created motion. The results are in table \ref{cycle_times_motion}

\begin{table}[ht]
  \begin{center}
    \begin{tabular}{| l | l |}
      \hline
      Cycle number & Length in milliseconds \\ \hline
      01 & 3101 \\ \hline
      02 & 3196 \\ \hline
      03 & 3131 \\ \hline
      04 & 3192 \\ \hline
      05 & 3147 \\ \hline
      06 & 3169 \\ \hline
      07 & 3201 \\ \hline
      08 & 3161 \\ \hline
      09 & 3207 \\ \hline
      10 & 3193 \\ \hline
    \end{tabular}
    \caption{Cycle times with motion}
  \end{center}
  \label{cycle_times_motion}
\end{table}

This time all cycles need to take two pictures in a row. This is because we have to reset the taken pictures after detecting motion (this is because the pictures no longer represent a still state and the camera has also rotated). Cycle time with motion averages to 3483 milliseconds, of which 2400 milliseconds are taken by raspistill calls. This leaves about 700 milliseconds for difference calculation and 300 milliseconds for rotation calculation. Here the cycle time is definately more than we would like.

\section{Improvements}

Improvements to the project can be made on software side of things. The following issues can be improved:

\begin{itemize}
  \item Slow camera usage: This issue can be resolved by implementing the used raspistill program in our own code. This can be done relatively easily as raspistill is an open source program and does not conflict with our software licensing (GPLv3). It merely requires time.
  \item Inaccurate motion detection algorithm: This issue is a bit harder to solve, but it can propably be done by precomputing static scenery and/or a set of three pictures for difference calculation. This way we should be able to know where the moving object is instead of the algorithm showing two moving objects (starting and end location of the moving object).
  \item Unstable audio calls: Resolving this issue requires a firmware fix to the Raspberry Pi. Should such fix be made available, we can easily update it to our project.
  \item Remote control: This is more a new feature than an existing issue. Remote control via network connection is easy to implement and allows some interesting use cases.
\end{itemize}

\end{document}

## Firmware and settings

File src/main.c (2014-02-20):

#include "audio.h"
#include "camera.h"
#include "motor.h"
#include "remote.h"
#include "logic.h"
#include "util.h"

#include <stdio.h>
#include <unistd.h>
#include <stdlib.h>
#include <string.h>

int main(int argc, char **argv)
{
	srand(time(NULL));

	remote_init();
	
	enable_logic();

	init_motors();
	init_samples("samples");

	while(1){
		logic_loop();
	}

	return 0;
}

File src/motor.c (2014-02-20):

#include "motor.h"

#include "gpio.h"
#include "util.h"
#include <time.h>
#include <math.h>
#include <stdio.h>

#ifndef M_PI
#define M_PI 3.14159265f
#endif

// angular velocities of motors
#define X_MOTOR_ANG_V 1.337f
#define X_MOTOR_DELTA_MAX (M_PI/8)

// motor radius delta
float x_motor_delta = 0.0f;

struct motor {
	int a;
	int b;
};

struct motor x_motor = {0, 1}; // GPIO0 = hardware 11 & GPIO1 hardware 12  

int init_motors()
{
	// enable output pins
	int result = 0;
	if (enable_output(x_motor.a) < 0) result = -1;
	if (enable_output(x_motor.b) < 0) result = -1;
	if (result < 0) {
		printf("Enabling motor output pins failed.\n");
		return -1;
	}
	// set pins to low by default
	set_low(x_motor.a);
	set_low(x_motor.b);

	return 0;
}

float safe_rad(float rad)
{
	if (x_motor_delta + rad > X_MOTOR_DELTA_MAX) {
		printf("DEBUG safe_rad: changing rad %f -> %f\n",
			rad, (X_MOTOR_DELTA_MAX - x_motor_delta));
		rad = X_MOTOR_DELTA_MAX - x_motor_delta;
	} else if (x_motor_delta + rad < -X_MOTOR_DELTA_MAX) {
		printf("DEBUG safe_rad: changing rad %f -> %f\n",
			rad, -(X_MOTOR_DELTA_MAX + x_motor_delta));
		rad = -(X_MOTOR_DELTA_MAX + x_motor_delta);
	}
	return rad;
}

void rotate_x(float rad)
{
	int turn_left = 0;
	rad = safe_rad(rad);
	if (rad == 0)
		return;
	
	x_motor_delta += rad;
	if (rad < 0) {
		rad = -rad;
		turn_left = 1;
	}
	float time = rad / X_MOTOR_ANG_V;
	
	if (turn_left) {
		printf("DEBUG rotate_x: turning LEFT %f seconds\n", time);
		set_low(x_motor.a);
		set_high(x_motor.b);
		delayms((int) (time * 1000)); // msec
		set_low(x_motor.b);
	} else {
		printf("DEBUG rotate_x: turning RIGHT %f seconds\n", time);
		set_low(x_motor.b);
		set_high(x_motor.a);
		delayms((int) (time * 1000)); // msec
		set_low(x_motor.a);
	}
}

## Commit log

2014-01-22 Audio amplifier design/schematics (Fritzing file).
    [audio_amplifier_lm386.fzz]
2014-01-23 L293D motor plan added
    [motor_controllers_l293d.fzz]
2014-01-23 Audio part of the requirements and design.
    [audio_amplifier_lm386.fzz]
2014-01-27 Added design for camera module.
2014-01-27 motors design added
    [motor_controllers_l293d.fzz]
2014-01-28 Fixed looping networking come when client interrupts to connection.
2014-01-30 Camera functionality stub.
2014-01-30 Added pclose to camera picture take (oops :D).
2014-01-30 motor controls with pins
2014-01-31 Changed camera functions to use BMP for storing.
2014-02-01 Initial implementation of motion detection.
    The most simple one with frame difference tests, contains difference
    threshold and noise filter options.
    Quite unsure if rasp can perform with this algorithm.
2014-02-06 fixes to sleep time in motor turning
    [main.c, motor.c]
2014-02-06 replaced gpio pin control from memhack to wiringPi. needs wiringPi lib to build. fix?
    [gpio.c, motor.c]
2014-02-13 wiringPi stub library and cmake funzies. atleast it builds :D
2014-02-13 enabling gpio pin control
2014-02-15 Added raspberry pi userland to used libraries.
2014-02-15 Proper sample playing logic.
    Will initialize the sample structure with files from samples directory.
    Logic will call audio lib to play one random sample from the structure.
2014-02-17 removed motor y code because motor y has been removed from the project
2014-02-17 correct turning velocity for motor
    [motor.c]
2014-02-17 Added magical number for motor input lag
2014-02-20 Changed motors to use gpio program via system call.
2014-02-20 cleaning up motor and gpio code, WiringPi lib is needed as a system requirement but it is not linked in our cmake
2014-02-20 added motor L293D schema implementation
    [motor_controllers_l293d_impl.fzz]
2014-02-20 evaluation documentation use case tests, and final report basic structure
2014-02-20 fixing use case tests
2014-02-20 Added timer to cycles (does not include audio and rotation).
2014-02-20 final report's motor related things
